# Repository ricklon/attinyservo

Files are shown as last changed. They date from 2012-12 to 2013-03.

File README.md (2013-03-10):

attinyservo
===========

Attiny Servo Board can easily be pogrammed by Arduino as ISP, and Arduino API

The through hole version is in the pth directory. The surface mount version is in the smt directory.

Arduino Core
====
* Attiny Core Google, https://code.google.com/p/arduino-tiny/
* Hi Tech LoTech Core, http://hlt.media.mit.edu/?p=1695
* 

Servo
====
* Servo Library: https://github.com/fri000/Servo8Bit
* Installation: http://www.cunningturtle.com/servo8bit-library-version-0-6-released/

Social Hardware:
=====
* Open Source
* Open Hardware
* Sharable

Licensing
====
The AttinyServo hardware is licenced under the Solderpad Hardware License v0.5.

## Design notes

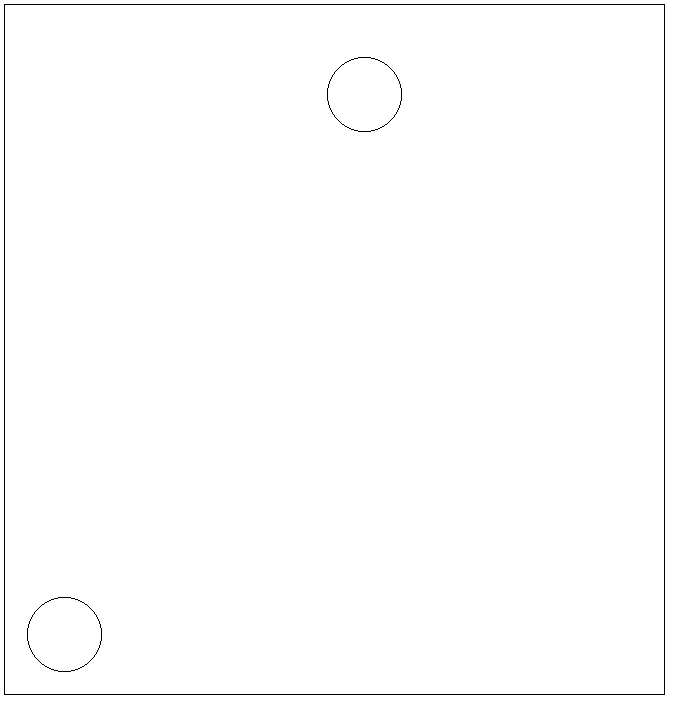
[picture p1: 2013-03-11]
smt/schematic/eagleUp/eagleUp_ATTinyServoSMT_v10_outline.png

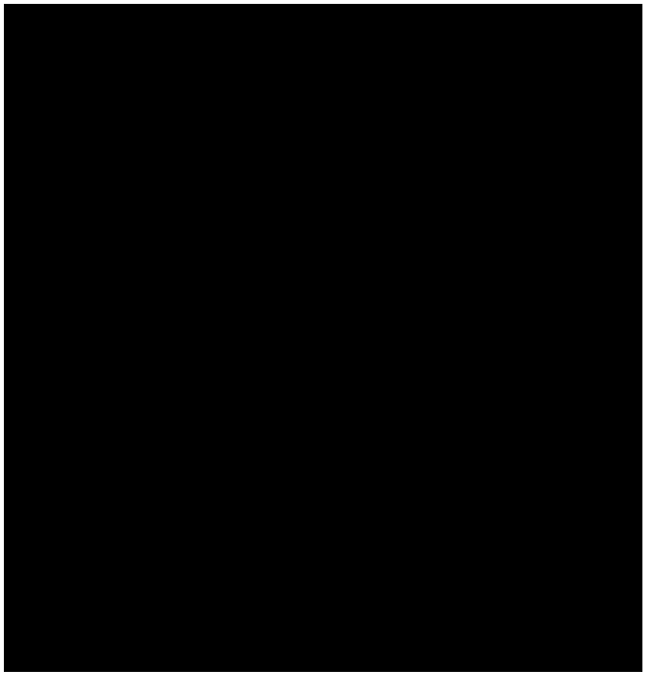
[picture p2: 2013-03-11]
smt/schematic/eagleUp/eagleUp_ATTinyServoSMT_v10_imagesize.png

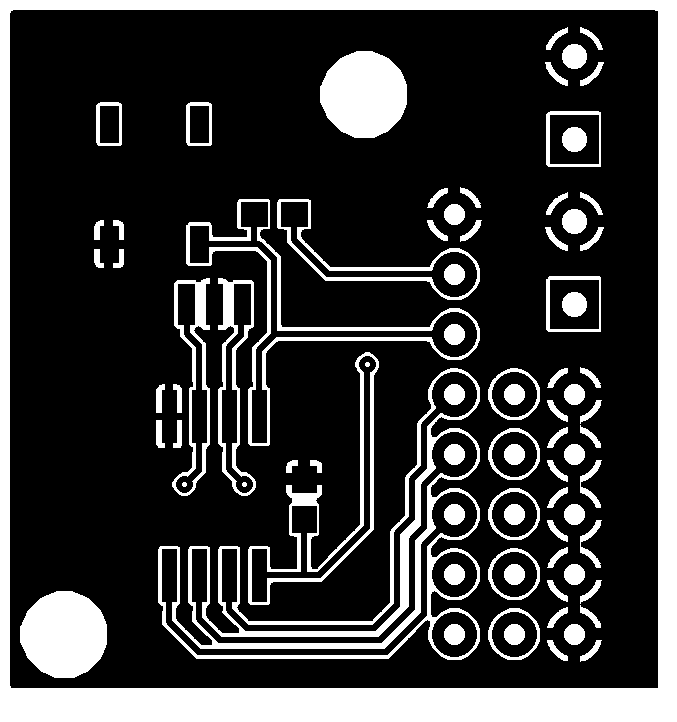
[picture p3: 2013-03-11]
smt/schematic/eagleUp/eagleUp_ATTinyServoSMT_v10_top.png

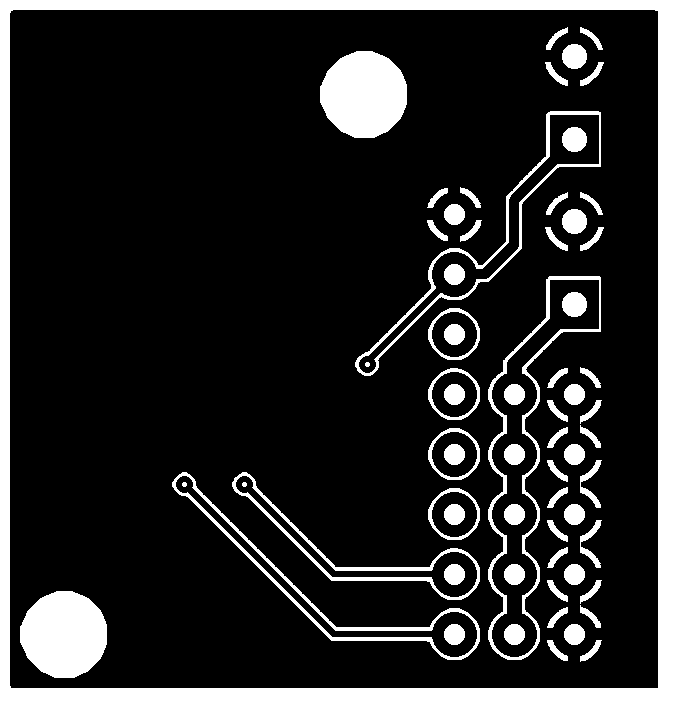
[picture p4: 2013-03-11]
smt/schematic/eagleUp/eagleUp_ATTinyServoSMT_v10_bottom.png

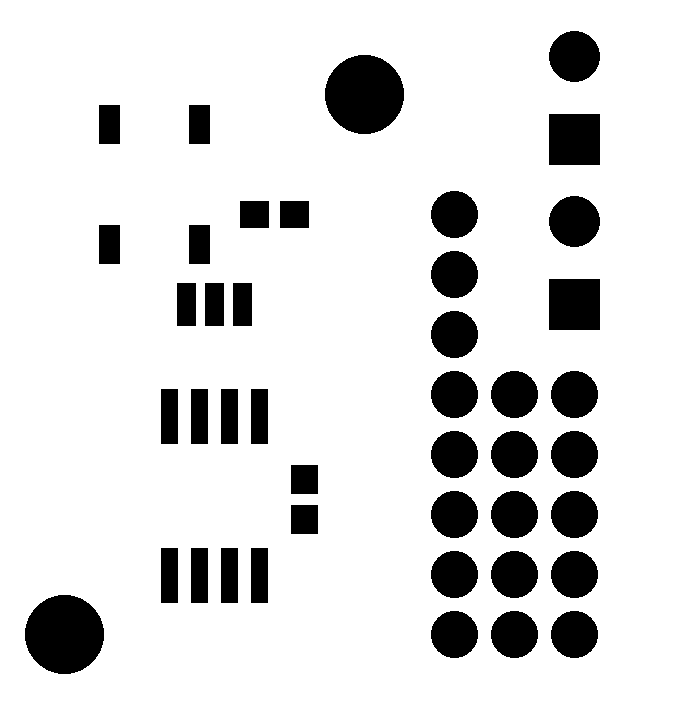
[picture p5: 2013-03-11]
smt/schematic/eagleUp/eagleUp_ATTinyServoSMT_v10_top_mask.png

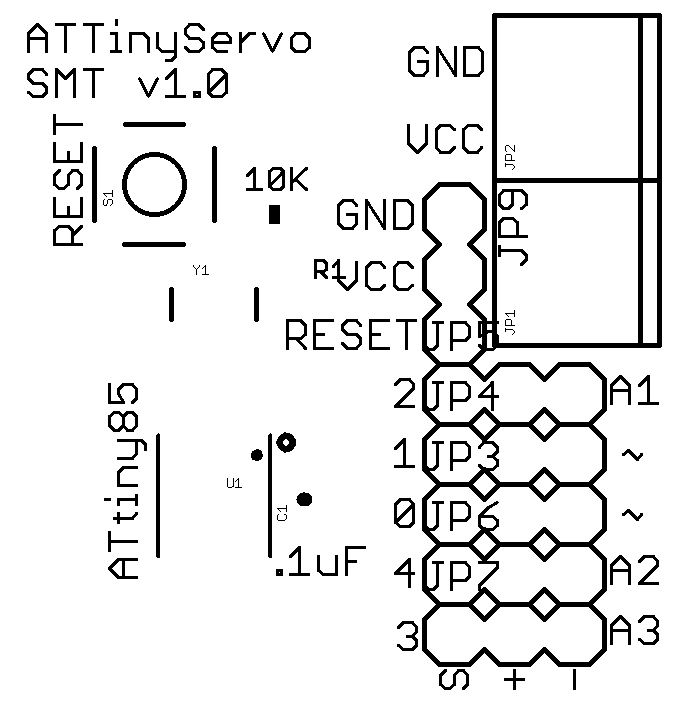
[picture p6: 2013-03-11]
smt/schematic/eagleUp/eagleUp_ATTinyServoSMT_v10_top_silk.png

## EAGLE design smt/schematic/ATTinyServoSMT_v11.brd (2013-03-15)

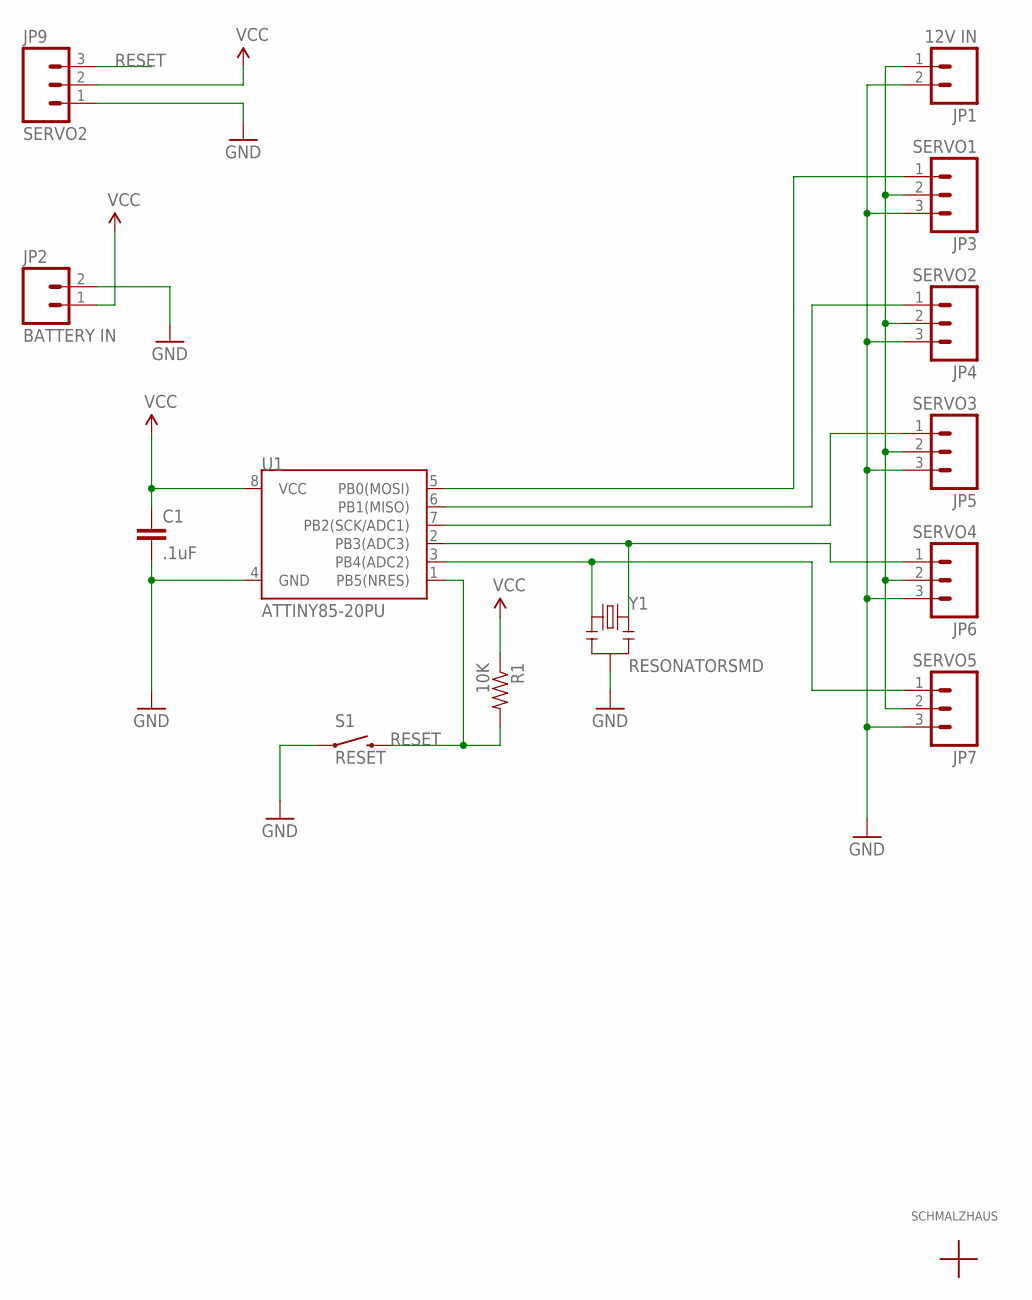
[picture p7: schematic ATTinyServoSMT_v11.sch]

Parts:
C1: .1uF; 0603-CAP
JP1: 12V IN; SCREWTERMINAL-3.5MM-2
JP2: BATTERY IN; SCREWTERMINAL-3.5MM-2
JP3: SERVO1; 1X03
JP4, JP9: SERVO2; 1X03
JP5: SERVO3; 1X03
JP6: SERVO4; 1X03
JP7: SERVO5; 1X03
R1: 10K; 0603-RES
S1: RESET; TACTILE_SWITCH_SMD
U1: ATTINY85-20PU; SO08-EIAJ
U$1: SCHMALZHAUSSCHMALZHAUS_SMALL; SCHMALZHAUS_SMALL
Y1: RESONATORSMD; RESONATOR-SMD

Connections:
GND: C1.2, JP1.2, JP2.2, JP3.3, JP4.3, JP5.3, JP6.3, JP7.3, JP9.1, S1.1, U1.4 (GND), Y1.2
unnamed: JP1.1, JP3.2, JP4.2, JP5.2, JP6.2, JP7.2
unnamed: JP6.1, U1.2 (PB3(ADC3)), Y1.3
unnamed: JP7.1, U1.3 (PB4(ADC2)), Y1.1
unnamed: JP5.1, U1.7 (PB2(SCK/ADC1))
unnamed: JP4.1, U1.6 (PB1(MISO))
unnamed: JP3.1, U1.5 (PB0(MOSI))
RESET: JP9.3, R1.2, S1.3 (2), U1.1 (PB5(NRES))
VCC: C1.1, JP2.1, JP9.2, R1.1, U1.8 (VCC)

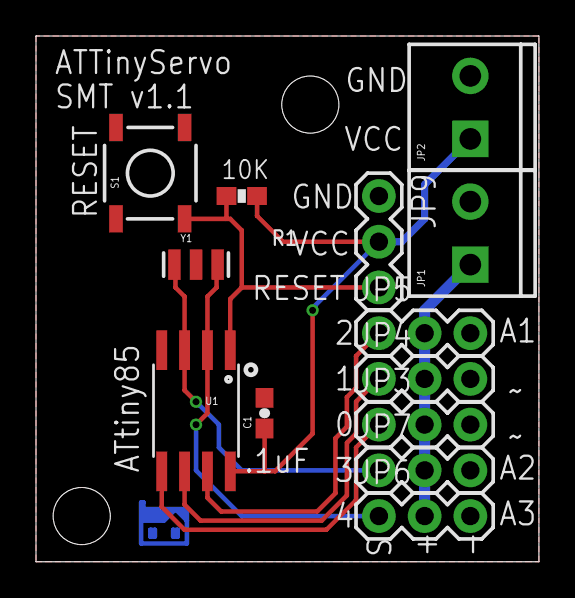
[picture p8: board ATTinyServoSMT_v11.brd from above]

Board: 2 copper layers, 27.9 x 29.2 mm, 14 parts (1 on the bottom side), 9 nets.

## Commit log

2012-12-19 Starter files added to project. In this version GND, Vcc reversed for chip power. Arduino ISP programming for the board shown in programming folder.
    [ATTinyServo_v10.brd, ATTinyServo_v10.sch, AttinyServoProgramming.fzz]
2012-12-19 added the image of the Fritzing file showing the wiring to program.
2013-03-06 Added programming, packaging, updated through hole version, and new smt version.
    [ATTinyServoSMT_v10.brd, ATTinyServoSMT_v10.sch, ATTinyServo_v11.brd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]
2013-03-06 Added the test gerbers, and sample image file.
    [ATTinyServoSMT_v10.GBL, ATTinyServoSMT_v10.GBO, ATTinyServoSMT_v10.GBP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]
2013-03-06 Reorganized the gerber files.
    [ATTinyServoSMT_v10.GBL, ATTinyServoSMT_v10.GBO, ATTinyServoSMT_v10.GBP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]
2013-03-07 Updated the images, and regenerated the gerbers -tNames layer.
2013-03-07 updated and added the gerbers directory.
    [ATTinyServoSMT_v10.GBL, ATTinyServoSMT_v10.GBO, ATTinyServoSMT_v10.GBP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]
2013-03-10 Fixed the Fritzing, and Image to have the reset pin connected by the capacitor. This prevents the Arduino from reseting when the reset for the Attiny85 is sent via ArduinoISP.
    [ATTinyServoSMT_v10.brd, AttinyServoProgramming.fzz]
2013-03-11 Update pins 3,4 to map correct to A2, A3.
    [ATTinyServoSMT_v11.brd, ATTinyServoSMT_v11.sch, ATTinyServo_v12.brd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]
2013-03-15 updated verisons and gerbers.
    [ATTinyServoSMT_v10.GBL, ATTinyServoSMT_v10.GBO, ATTinyServoSMT_v10.GBP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]
2014-11-07 Updated the Fritizing file. Added mega configuration.
    [AttinyServoProgramming.fzz]
2014-11-07 updated the mega fritzing.
    [AttinyServoProgrammingMega.fzz]

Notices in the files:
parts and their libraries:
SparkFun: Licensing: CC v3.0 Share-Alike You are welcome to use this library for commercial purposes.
